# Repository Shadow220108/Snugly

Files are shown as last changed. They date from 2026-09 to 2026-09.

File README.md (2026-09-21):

## Snugly 



# What is it?

its a macropad or better known as a hackpad, unlike normal pico or esp32 s3 we used barebones rp2040 which is a well known chip also used in pico, but we wired it bare bones giving us a more better control over our hardware and space (and also cheap)

# why

macropad is REALLY useful when you have a 60% keyboard, also handy when you are bad at learning shortcuts (really handy)

# how does it work

using rp2040, the rust firmware inits and starts the system clock... the basic firmware currently shows total clicks on display and everytime you click a switch the led gets brighter and brighter

# motivation

WE relly loved the hackpad in blueprint and decided to make one of our own but significantly cheaper and better!

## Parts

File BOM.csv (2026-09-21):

Product | Quantity | Price
PCBs | 5 ( MOQ ) | 4$
PCBA | 2 ( MOQ ) | 52.99$
Cherry MX Switches | Set of 10 | 3.70$
Keycaps | Set of 10 | 1.50$
Rotary Encoder | 1 | 0.30$
0.91" Inch OLED | 1 | 3.50$
 | Total | 66$

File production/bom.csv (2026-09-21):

Designator | Footprint | Quantity | Value | LCSC Part #
C1, C11, C12, C17, C2, C3, C4, C5, C6, C7, C8 | 0402 | 11 | 0.1uF
C10, C9 | 0402 | 2 | 1uF
C13, C14 | 0402 | 2 | 10uF
C15, C16 | 0402 | 2 | 15pF
D1, D2, D3, D4, D5, D6, D7, D8, D9 | 0402 | 9 | 1N4148
D10, D11, D12, D13, D14, D15, D16, D17, D18 | LED_WS2812B_PLCC4_5.0x5.0mm_P3.2mm | 9 | WS2812B
J1 | USB_C_Receptacle_HCTL_HC-TYPE-C-16P-01A | 1 | USB_C_Receptacle_USB2.0_16P
R1, R2 | 0402 | 2 | 5.1k
R3, R4 | 0402 | 2 | 27
R5, R6 | 0402 | 2 | 1k
R7 | 0402 | 1 | 10k
SW1 | SW-SMD_4P-L3.0-W2.6-P1.80-LS3.4-TL | 1 | SW_Push | C778132
SW10, SW2, SW3, SW4, SW5, SW6, SW7, SW8, SW9 | SW_Cherry_MX_1.00u_PCB | 9 | SW_Push
SW11 | RotaryEncoder_Alps_EC11E-Switch_Vertical_H20mm | 1 | RotaryEncoder_Switch
U1 | QFN-56-1EP_7x7mm_P0.4mm_EP3.2x3.2mm | 1 | RP2040
U2 | SOT-223-3_TabPin2 | 1 | NCP1117-3.3_SOT223
U3 | WSON-8_L6.0-W5.0-P1.27-BL-EP | 1 | W25Q16JVSS | C2456208
U4 | ER_OLEDM0.91_1x-I2C | 1 | 0.91 Inch OLED
Y1 | CRYSTAL-SMD_4P-L3.2-W2.5-BL | 1 | 12MHz | C9002

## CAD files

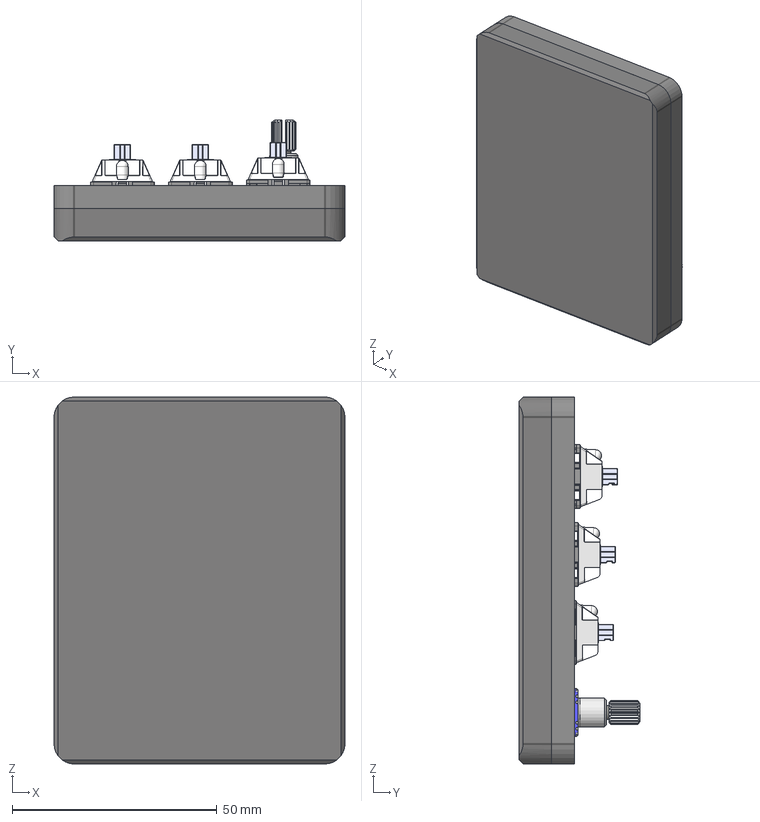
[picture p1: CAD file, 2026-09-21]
CAD/snugly_assembled.step
71.1 x 29.6 x 89.7 mm

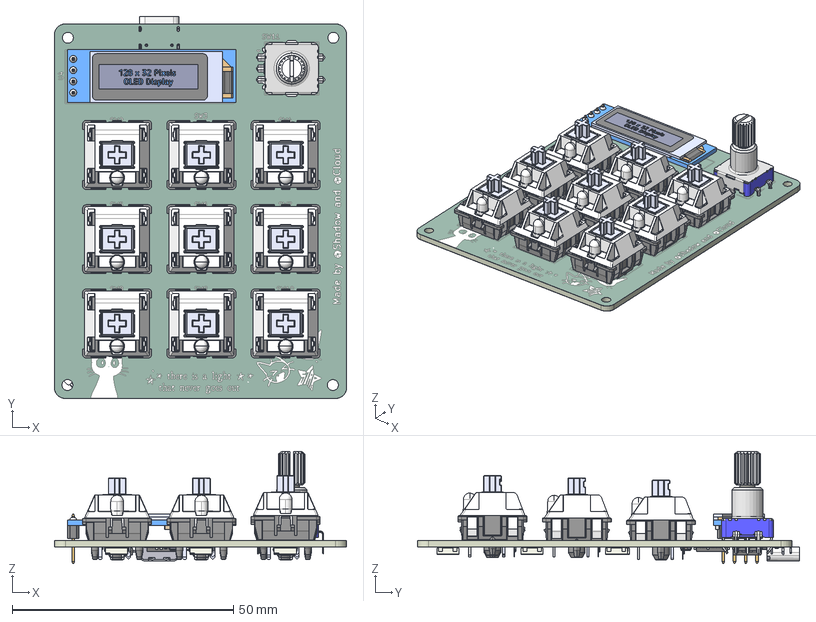
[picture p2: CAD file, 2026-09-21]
CAD/snugly_pcb_allmodels.step
66.1 x 86.3 x 25.4 mm
Bottom x 9
Pulsador x 9
Top x 9
Pieza5^Cherry MX x 9
Pin1 x 9
Pin2 x 9
Led 3mm_trans x 9
Board_001
1x4 Male Header_001
0603 Capacitor_001
0603 Capacitor_002
0603 Capacitor_003
0603 Capacitor_004
0603 Capacitor_005
0603 Capacitor_006
0603 Capacitor_007
0603 Capacitor_008
0603 Resistor_001
0603 Resistor_002
0603 Resistor_003
0603 Resistor_004
0603 Resistor_005
Surface Mount Transistor_001
EC11 Rotary Encoder Dode Switch-15mm
C_0402_1005Metric x 26
R_0402_1005Metric x 7
LED_WS2812B_PLCC4_5.0x5.0mm_P3.2mm x 9
tongue
shield
contact_001
contact_002
contact_003
contact_004
contact_court_001
contact_court_002
contact_court_003
contact_court_004
contact_005
contact_006
contact_007
contact_008
contact_court_005
contact_court_006
contact_court_007
contact_court_008
pin_001
pin_002
pin_003
pin_004
pin_005
pin_006
pin_007
pin_008
pin_009
pin_010
pin_011
pin_012
pin_013
pin_014
pin_015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

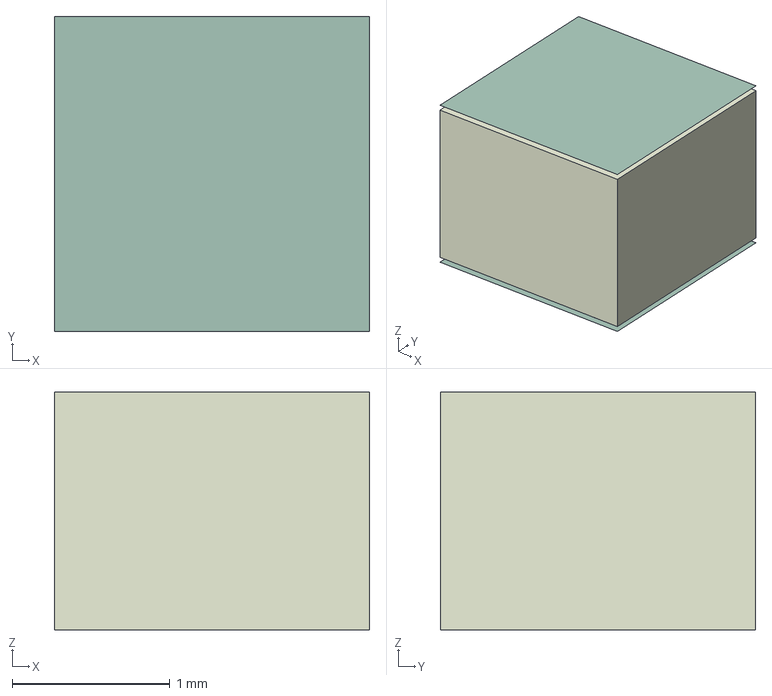
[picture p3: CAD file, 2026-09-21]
PCB/snugly_pcb.step
2.00 x 2.00 x 1.61 mm
snugly_soldermask x 2
snugly_PCB

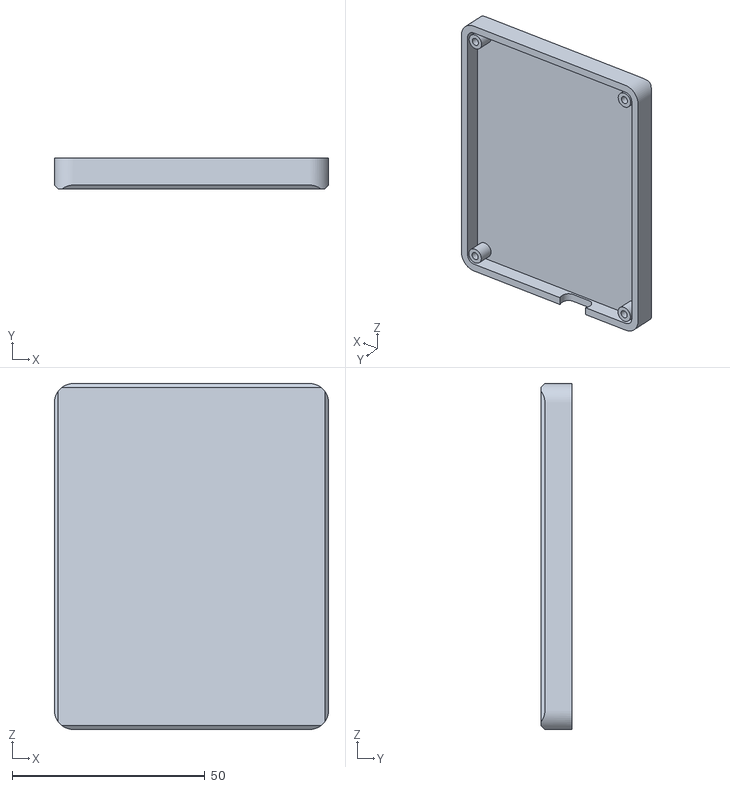
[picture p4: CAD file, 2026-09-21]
production/snuglybottom.stl
71.1 x 8.00 x 89.7

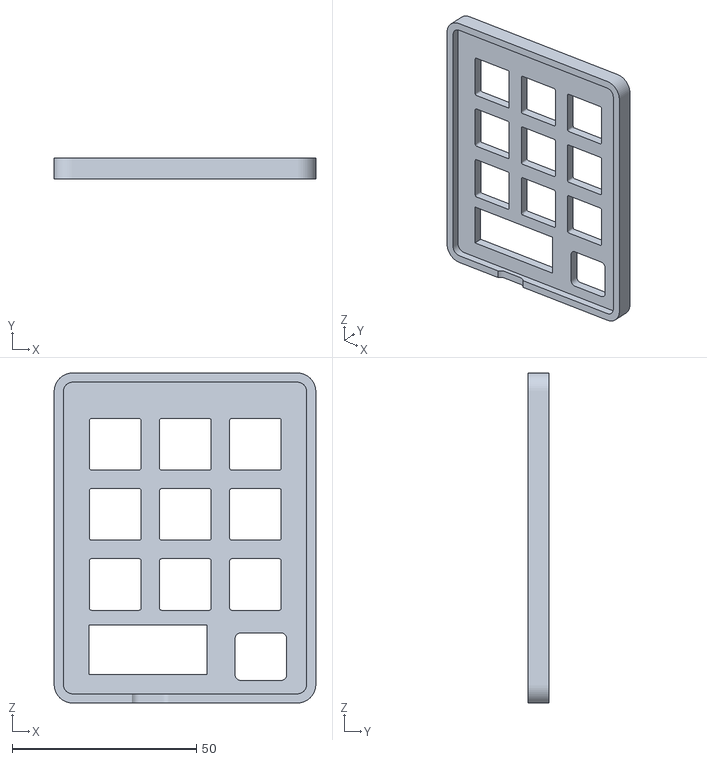
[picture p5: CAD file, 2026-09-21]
production/snuglytop.stl
71.1 x 5.59 x 89.7

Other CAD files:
CAD/snugly.f3d

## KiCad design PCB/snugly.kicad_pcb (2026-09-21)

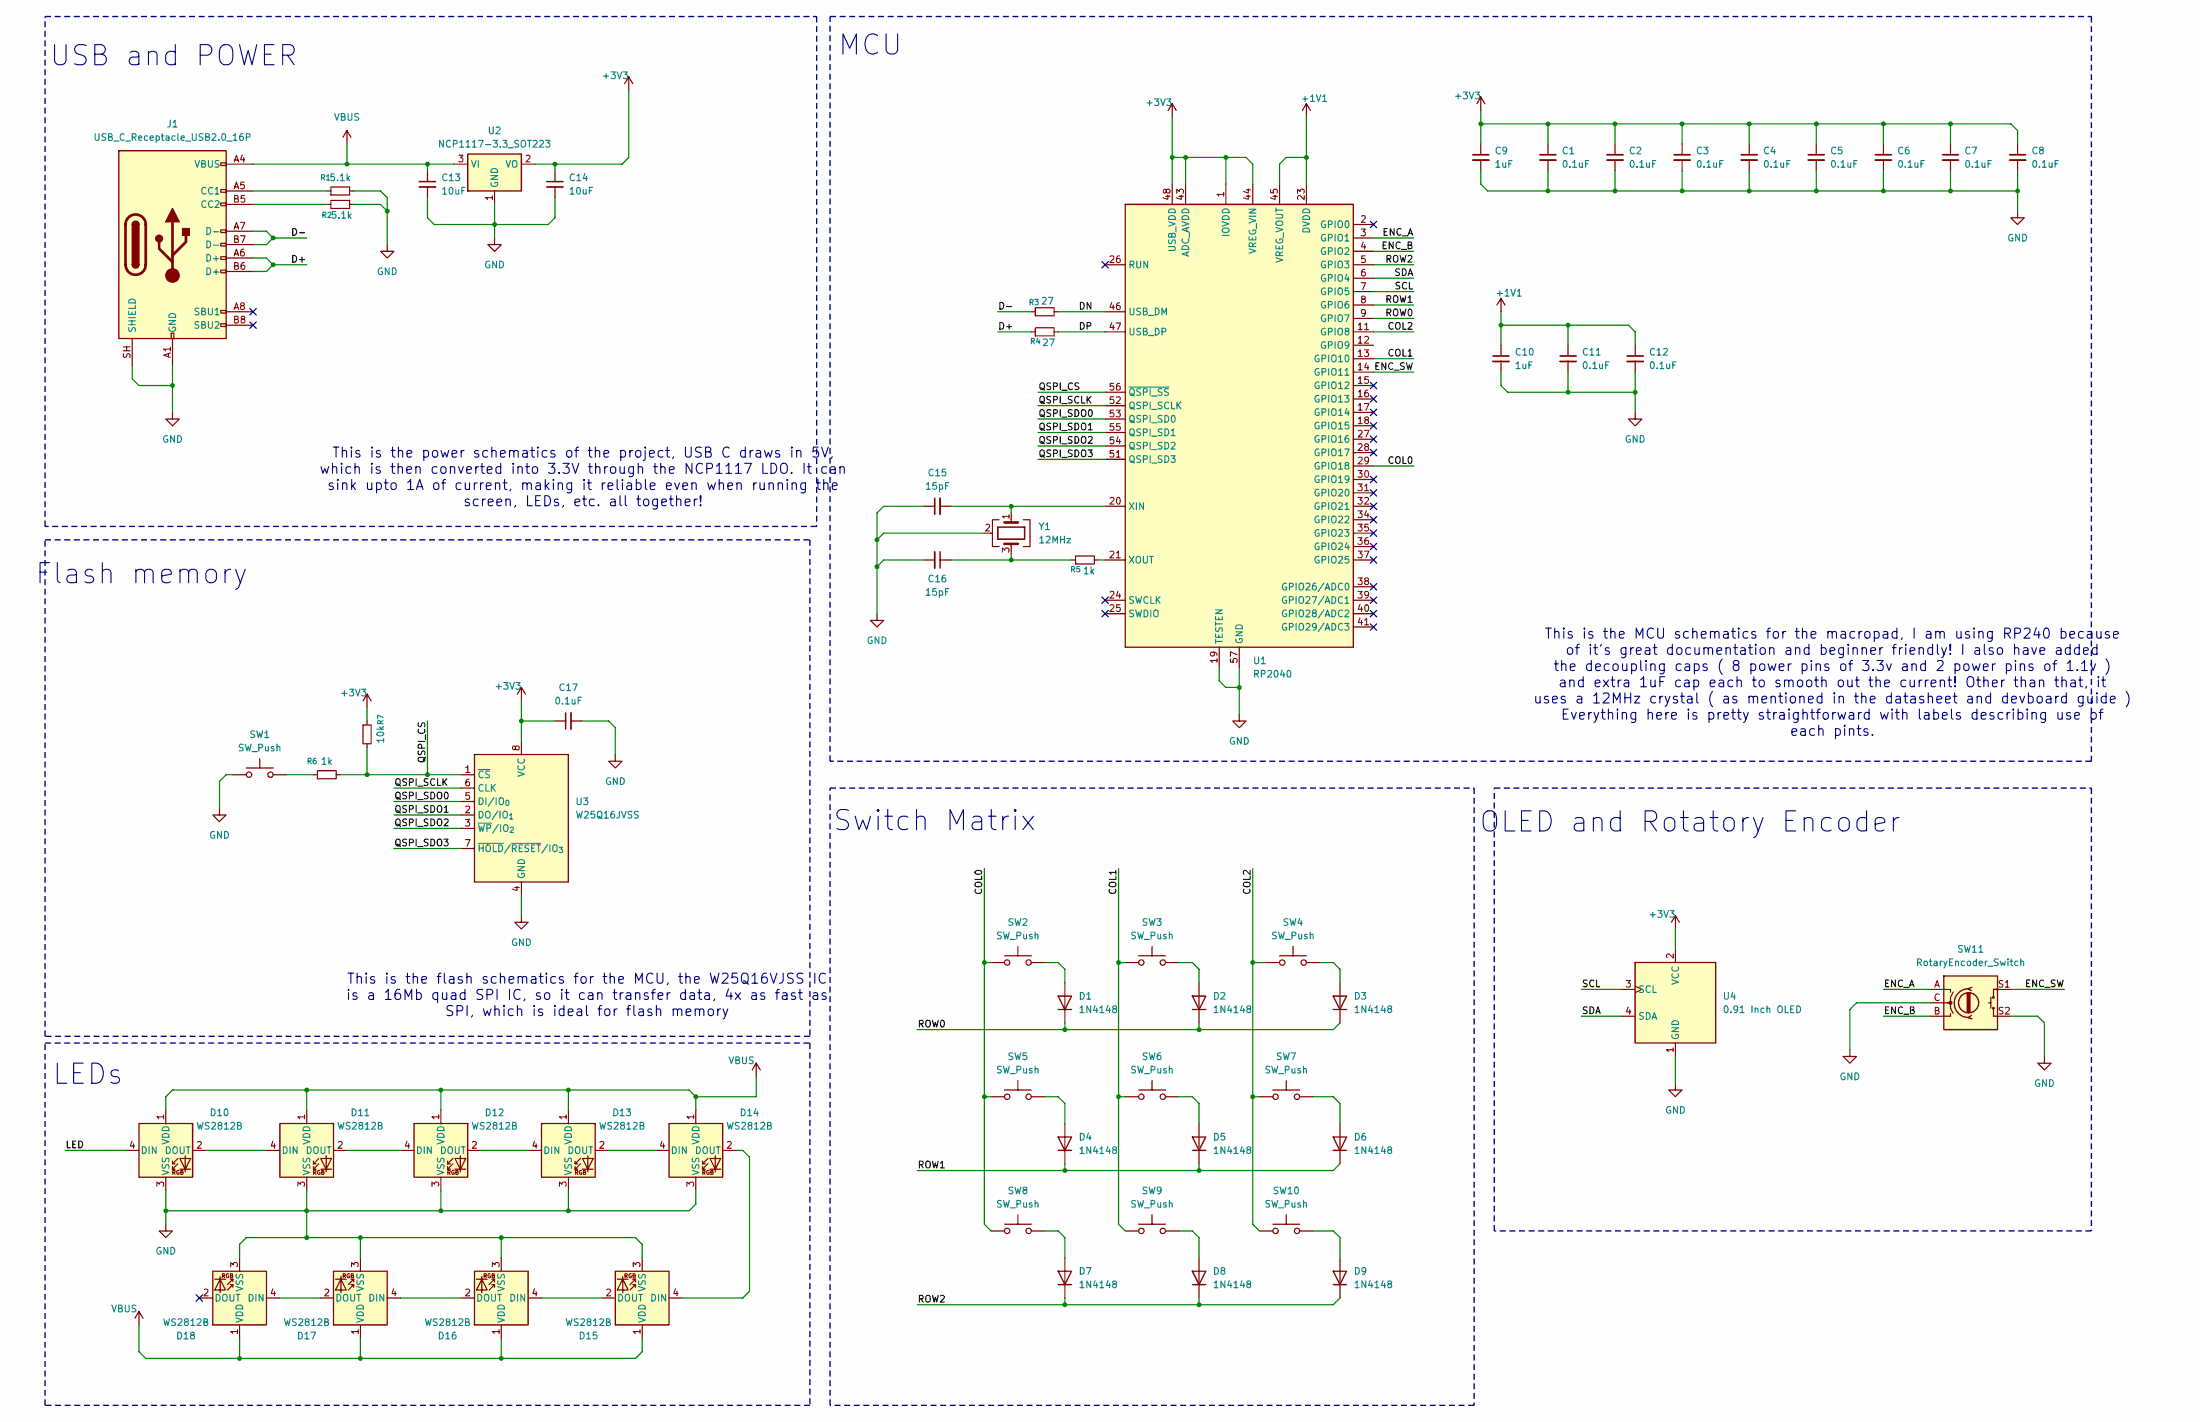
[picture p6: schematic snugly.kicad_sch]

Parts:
C1, C2, C3, C4, C5, C6, C7, C8, C11, C12, C17: 0.1uF; C_0402_1005Metric
C9, C10: 1uF; C_0402_1005Metric
C13, C14: 10uF; C_0402_1005Metric
C15, C16: 15pF; C_0402_1005Metric
D1, D2, D3, D4, D5, D6, D7, D8, D9: 1N4148; C_0402_1005Metric
D10, D11, D12, D13, D14, D15, D16, D17, D18: WS2812B; LED_WS2812B_PLCC4_5.0x5.0mm_P3.2mm
J1: USB_C_Receptacle_USB2.0_16P; USB_C_Receptacle_HCTL_HC-TYPE-C-16P-01A
R1, R2: 5.1k; R_0402_1005Metric
R3, R4: 27; R_0402_1005Metric
R5, R6: 1k; R_0402_1005Metric
R7: 10k; R_0402_1005Metric
SW1: SW_Push; SW-SMD_4P-L3.0-W2.6-P1.80-LS3.4-TL
SW2, SW3, SW4, SW5, SW6, SW7, SW8, SW9, SW10: SW_Push; SW_Cherry_MX_1.00u_PCB
SW11: RotaryEncoder_Switch; RotaryEncoder_Alps_EC11E-Switch_Vertical_H20mm
U1: RP2040; QFN-56-1EP_7x7mm_P0.4mm_EP3.2x3.2mm
U2: NCP1117-3.3_SOT223; SOT-223-3_TabPin2
U3: W25Q16JVSS; WSON-8_L6.0-W5.0-P1.27-BL-EP
U4: 0.91 Inch OLED; ER_OLEDM0.91_1x-I2C
Y1: 12MHz; CRYSTAL-SMD_4P-L3.2-W2.5-BL

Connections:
+1V1: C10.1, C11.1, C12.1, U1.23 (DVDD), U1.45 (VREG_VOUT), U1.50 (DVDD)
+3V3: C1.1, C2.1, C3.1, C4.1, C5.1, C6.1, C7.1, C8.1, C9.1, C14.1, C17.1, R7.1, U1.1 (IOVDD), U1.10 (IOVDD), U1.22 (IOVDD), U1.33 (IOVDD), U1.42 (IOVDD), U1.43 (ADC_AVDD), U1.44 (VREG_VIN), U1.48 (USB_VDD), U1.49 (IOVDD), U2.2 (VO), U3.8 (VCC), U4.2 (VCC)
/COL0: SW2.1, SW5.1, SW8.1, U1.29 (GPIO18)
/COL1: SW3.1, SW6.1, SW9.1, U1.13 (GPIO10)
/COL2: SW4.1, SW7.1, SW10.1, U1.11 (GPIO8)
/D+: J1.A6 (D+), J1.B6 (D+), R4.1
/D-: J1.A7 (D-), J1.B7 (D-), R3.1
/DN: R3.2, U1.46 (USB_DM)
/DP: R4.2, U1.47 (USB_DP)
/ENC_A: SW11.A, U1.3 (GPIO1)
/ENC_B: SW11.B, U1.4 (GPIO2)
/ENC_SW: SW11.S1, U1.14 (GPIO11)
/LED: D10.4 (DIN)
/QSPI_CS: R6.2, R7.2, U1.56 (~QSPI_SS), U3.1 (~CS)
/QSPI_SCLK: U1.52 (QSPI_SCLK), U3.6 (CLK)
/QSPI_SDO0: U1.53 (QSPI_SD0), U3.5 (DI/IO_{0})
/QSPI_SDO1: U1.55 (QSPI_SD1), U3.2 (DO/IO_{1})
/QSPI_SDO2: U1.54 (QSPI_SD2), U3.3 (~WP/IO_{2})
/QSPI_SDO3: U1.51 (QSPI_SD3), U3.7 (~HOLD/~RESET/IO_{3})
/ROW0: D1.1 (K), D2.1 (K), D3.1 (K), U1.9 (GPIO7)
/ROW1: D4.1 (K), D5.1 (K), D6.1 (K), U1.8 (GPIO6)
/ROW2: D7.1 (K), D8.1 (K), D9.1 (K), U1.5 (GPIO3)
/SCL: U1.7 (GPIO5), U4.3 (SCL)
/SDA: U1.6 (GPIO4), U4.4 (SDA)
GND: C1.2, C2.2, C3.2, C4.2, C5.2, C6.2, C7.2, C8.2, C9.2, C10.2, C11.2, C12.2, C13.2, C14.2, C15.1, C16.2, C17.2, D10.3 (VSS), D11.3 (VSS), D12.3 (VSS), D13.3 (VSS), D14.3 (VSS), D15.3 (VSS), D16.3 (VSS), D17.3 (VSS), D18.3 (VSS), J1.A1 (GND), J1.A12 (GND), J1.B1 (GND), J1.B12 (GND), J1.SH (SHIELD), R1.2, R2.1, SW1.1, SW11.C, SW11.S2, U1.19 (TESTEN), U1.57 (GND), U2.1 (GND), U3.4 (GND), U4.1 (GND), Y1.2 (G), Y1.4 (G)
unnamed: C16.1, R5.1, Y1.3
unnamed: D1.2 (A), SW2.2
unnamed: D2.2 (A), SW3.2
unnamed: D3.2 (A), SW4.2
unnamed: D4.2 (A), SW5.2
unnamed: D5.2 (A), SW6.2
unnamed: D6.2 (A), SW7.2
unnamed: D7.2 (A), SW8.2
unnamed: D8.2 (A), SW9.2
unnamed: D9.2 (A), SW10.2
unnamed: D10.2 (DOUT), D11.4 (DIN)
unnamed: D11.2 (DOUT), D12.4 (DIN)
unnamed: D12.2 (DOUT), D13.4 (DIN)
unnamed: D13.2 (DOUT), D14.4 (DIN)
unnamed: D14.2 (DOUT), D15.4 (DIN)
unnamed: D15.2 (DOUT), D16.4 (DIN)
unnamed: D16.2 (DOUT), D17.4 (DIN)
unnamed: D17.2 (DOUT), D18.4 (DIN)
unnamed: J1.A5 (CC1), R1.1
unnamed: J1.B5 (CC2), R2.2
unnamed: R6.1, SW1.2
unnamed: C15.2, U1.20 (XIN), Y1.1
unnamed: R5.2, U1.21 (XOUT)
VBUS: C13.1, D10.1 (VDD), D11.1 (VDD), D12.1 (VDD), D13.1 (VDD), D14.1 (VDD), D15.1 (VDD), D16.1 (VDD), D17.1 (VDD), D18.1 (VDD), J1.A4 (VBUS), J1.A9 (VBUS), J1.B4 (VBUS), J1.B9 (VBUS), U2.3 (VI)

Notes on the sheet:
Switch Matrix
USB and POWER
OLED and Rotatory Encoder
This is the power schematics of the project, USB C draws in 5V, which is then converted into 3.3V through the NCP1117 LDO. It can sink upto 1A of current, making it reliable even when running the screen, LEDs, etc. all together!
Flash memory
This is the flash schematics for the MCU, the W25Q16VJSS IC is a 16Mb quad SPI IC, so it can transfer data, 4x as fast as SPI, which is ideal for flash memory
This is the MCU schematics for the macropad, I am using RP240 because of it's great documentation and beginner friendly! I also have added the decoupling caps ( 8 power pins of 3.3v and 2 power pins of 1.1v ) and extra 1uF cap each to smooth out the current! Other than that, it uses a 12MHz crystal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
LEDs
MCU

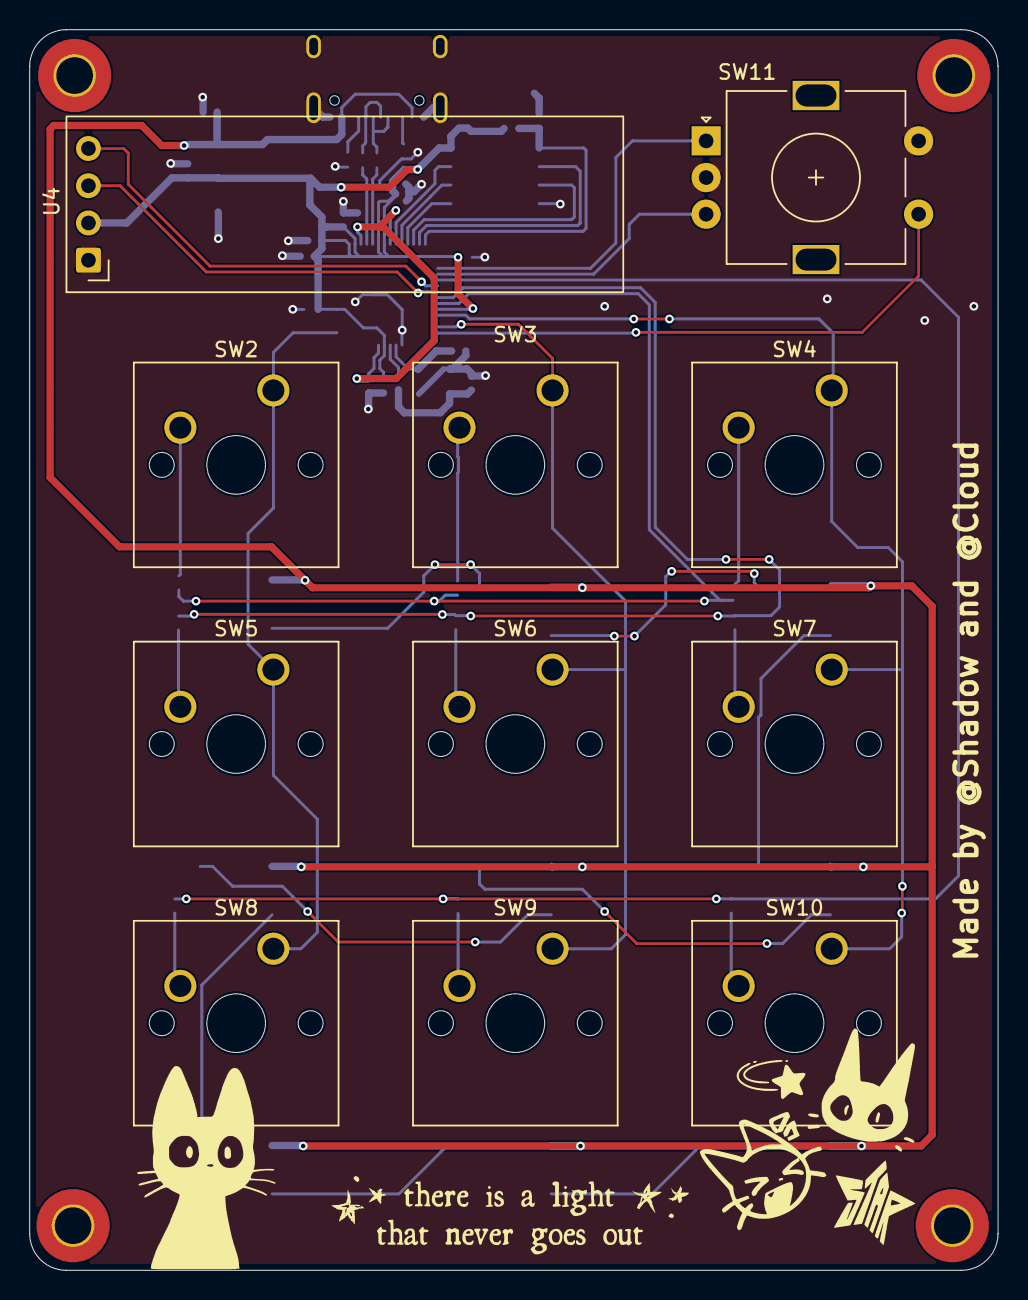
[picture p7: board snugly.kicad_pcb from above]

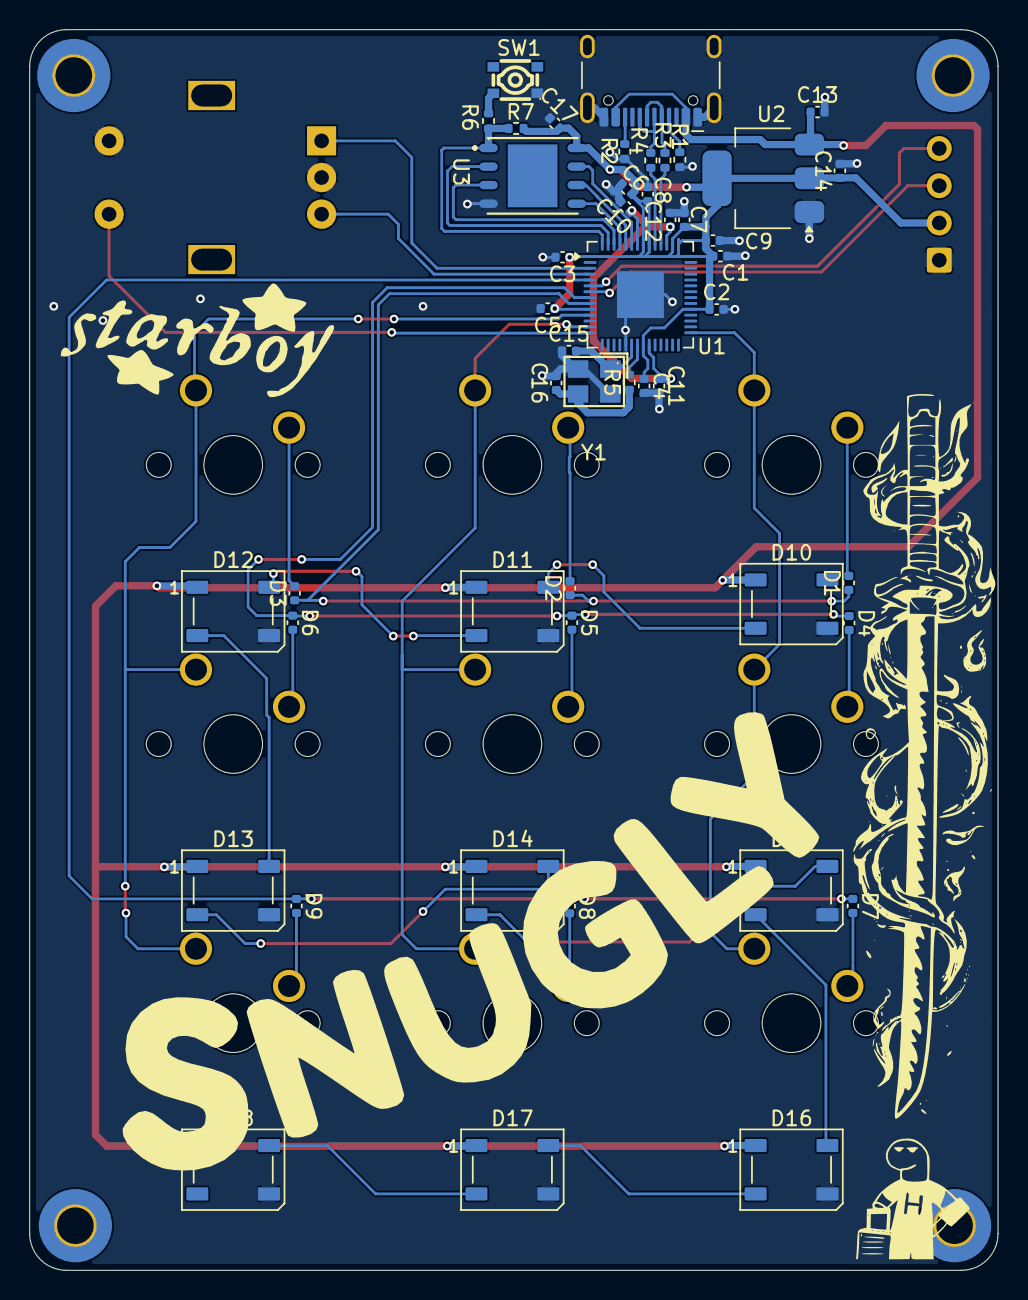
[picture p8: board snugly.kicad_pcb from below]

Board: 2 copper layers, 66.1 x 84.7 mm, 59 parts (48 on the bottom side), 48 nets.

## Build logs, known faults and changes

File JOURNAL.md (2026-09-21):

## Snugly

### Total Time Spent :

---

### Journal #1 : Completing the schematics!

#### Total time : 2 hours 5 mins

#### By @Shadow

Starting with the project, the first plan was to make the schematics! For this hackpad, I am designing a PCB with a custom
integrated MCU rather than using a premade module such as the Xiao RP2040, for the MCU, I will be using the beginner friendly
RP2040 MCU, I started by adding the symbol to KiCAD and wiring it up! I used help of the custom devboard guide by Kai Pierra,
and the official datasheet!

| MCU                                                                                                     |
| ------------------------------------------------------------------------------------------------------- |
| mcu |

It will be powered by USB C, providing it with 5V which is then stepped down to 3.3V with the use of LDO, other than that it
uses 16Mb quad SPI flash memory making it 4 times as fast as single SPI memory!

| Power and Flash                                                                                           |
| --------------------------------------------------------------------------------------------------------- |
| power |

The hackpad will have a 3 by 3 matrix of total 9 keys, with individual RGB LED ( WS2812B ) for all the keys! It also consists of
a Rotatory Encoder and 0.91" Inch OLED!

### Journal #2 : Making the Bootup Art

#### Total time : 3h~

#### By @cloudglides

For the bootup screen of the hackpad, I wanted to make some custom art instead of using a basic logo or text. I decided to make an Orpheus themed art for it.

I first made Orpheus holding a booklet, but later changed the idea and made him hold a PCB instead. This fit the project much better since the hackpad is a hardware project and the PCB is an important part of it.

| ophie                                                                                                     |
| --------------------------------------------------------------------------------------------------------- |
| power |

I made the art specifically to be used on the hackpads bootup screen.

### Journal #3 : Adding footprints and working on PCB

#### Total time : 2h 15 mins

#### By @Shadow

After being done with the Schematics, I started with adding the footprints, to keep the MCU side compact and easy to route, I am using 0402 footprint for capacitors and resistors, I started routing the PCB, starting with the power side first, I tried to place the decoupling capacitors first, after a few tries I got it!

| PCB                                                                                                                               |
| --------------------------------------------------------------------------------------------------------------------------------- |
|  |

I am trying to keeep all the components on bottom layer of PCB and have a clean routing, and use the top layer for a clean ground plane and power schematics!

| PCB again                                                                                                                                                  |
| ---------------------------------------------------------------------------------------------------------------------------------------------------------- |
|  |

### Journal #4 : Writing firmware and working on canva

#### Total time : 5h~

#### By @cloudglides

im done firmware pretty much... its 5AM and im not right on mind? i believe i used a rust lib to write the firmware from scratch (not technically)- but okay i also tried writing some unit tests in `lib.rs` but apparently you cant really write decent unit tests in hw so i gave up, (should have known earlier)... about canva i was working on a zine to use later in a readme but im not really complete and really tired for my mind to work decently... im so glad my exam is tommorow otherwise i would have fumbled today really bad- leaving that apart my thought process in canva is really pretty much FAFO... i try alot of new things remove them and iterate upon them again and thats how i make my good softwares... about rust it wont work unless you have rustup installed and are a nerd since you also have to resolve some path... pretty much why i am nit a big fan of this but it is what it is

### Journal #5 : Writing firmware

#### Total time : 3h~

#### By @cloudglides

worked on firmware once again, pretty much again worked on making it more efficient and running some animations on the oled.. pretty fun though im not aware about how good it will look as i dont have access to the hardware
apart from that i did very little art, needed a few iterations on the original work

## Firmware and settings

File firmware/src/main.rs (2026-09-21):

#![no_std]
#![no_main]
use rp2040_hal::Clock;
use rp2040_hal::clocks::ClockSource;
use embedded_hal::digital::{InputPin, OutputPin};
use cortex_m_rt::entry;
use panic_halt as _;

use rp2040_hal::{
    clocks::init_clocks_and_plls,
    gpio::Pins,
    pac,
    sio::Sio,
    watchdog::Watchdog,
};

#[entry]

fn main() -> ! {
    let mut pac = pac::Peripherals::take().unwrap();
    let mut watchdog = Watchdog::new(pac.WATCHDOG);


    let clocks = init_clocks_and_plls(
        12_000_000,
        pac.XOSC,
        pac.CLOCKS,
        pac.PLL_SYS,
        pac.PLL_USB,
        &mut pac.RESETS,
        &mut watchdog,
    )
    .ok().unwrap();

    let sio = Sio::new(pac.SIO);

    let pins = Pins::new(
        pac.IO_BANK0,
        pac.PADS_BANK0,
        sio.gpio_bank0,
        &mut pac.RESETS,
    );



    let mut led = pins.gpio25.into_push_pull_output();
    let mut led2 = pins.gpio26.into_push_pull_output();
    let mut led3 = pins.gpio27.into_push_pull_output();
    let mut led4 = pins.gpio28.into_pull_up_input();
    let mut key = pins.gpio0.into_pull_up_input();
    let sda = pins.gpio4.into_function::<rp2040_hal::gpio::FunctionI2C();
    let scl = pins.gpio5.into_function::<rp2040_hal::gpio::FunctionI2C();
    let mut presses = 0;
    let mut progress = 0;
    
    loop {
        if key.is_low().unwrap(){
            presses+=1;
            progress+=10;

           
            led.set_high().unwrap();
            if presses == 1{
                led.set_high().unwrap()
            } elif presses == 2{
                led2.set_high().unwrap()
            } elif presses == 3{
                led3.set_high().unwrap()
            } elif presses == 4{
                led4.set_high().unwrap()
            }

            cortex_m::asm::delay(
                clocks.system_clock.freq().to_Hz() / (10 + presses.min(10))
            );

            use embedded_graphics::{
                mono_font::{ascii::FONT_6X10, MonoTextStyle},
                pixelcolor::BinaryColor,
                prelude::*,
                text::Text,
            };

            use ssd1306::{prelude::*, I2CDisplayInterface, Ssd1306};
            let interface = I2CDisplayInterface::new(i2c);

            let mut display = Ssd1306::new(
                interface,
                DisplaySize128x32,
                DisplayRotation::Rotate0,
            ).into_buffered_graphics_mode();


            let text_style = MonoTextStyle::new(&FONT_6X10,BinaryColor::On);


            let mut x = 0;
            let mut y = 0;

            let mut dx = 0;
            let mut dy = 0;

            
            display.clear(BinaryColor::Off).unwrap();

            Circle::new(Point::new(x,y), 8)
                .into_styled(PrimitiveStyle::with_fill(BinaryColor::On))
                .draw(&mut display)
                .unwrap();

            display.flush().unwrap();

            Rectangle::new(
                Point::new(12,10),
                Size::new(progress, 9)
            ).into_styled(
            PrimitiveStyle::with_fill(BinaryColor::On)
            ).draw(&mut display).unwrap();
            
            display.flush().unwrap();

            progress+=2;

            if progress>104{
                progress = 0;
            }

            cortex_m::asm::delay(
                clocks.system_clock.freq().to_Hz() / 60
            )

            x += dx;
            y += dy;

            if x <= 0|| x >= 120{
                dx = -dx;
            }
            if y<=0 || y>= 120{
                dy = -dy;
            }

            cortex_m::asm::delay(
                clocks.system_clock.freq().to_Hz() / 60 
            )
            Text::new(
                "Hello From {progress}!!",
                Point::new(10,30),
                text_style,
            ).draw(&mut display).unwrap();

            led.set_low().unwrap();
            led1.set_low().unwrap();
            led2.set_low().unwrap();
            led3.set_low().unwrap();
            let4.set_low().unwrap();


            while key.is_low().unwrap() {}

            cortex_m::asm::delay(
                clocks.system_clock.freq().to_Hz() / 100
            );
        }
    };
}
